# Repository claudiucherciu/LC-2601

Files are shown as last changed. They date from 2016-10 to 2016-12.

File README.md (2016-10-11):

# LibreCube LC-2601 GPS Module

## Overview
The LC-2601 GPS Module is a standalone board that integrates an
GPS receiver and makes its output in terms of position, altitude,
and time available via the CAN bus interface.

## Authors
* Claudiu Cherciu <claudiucherciu@gmail.com>
* Dominik Marszk <dmarszk@gmail.com>
* Artur Scholz <artur.scholz@cubesat.de>

## Acknowledgements
Supported by the ESOC Cybernetic Club.
*SMA connector library from http://www.kicadlib.org/modules/sma_connectors.zip

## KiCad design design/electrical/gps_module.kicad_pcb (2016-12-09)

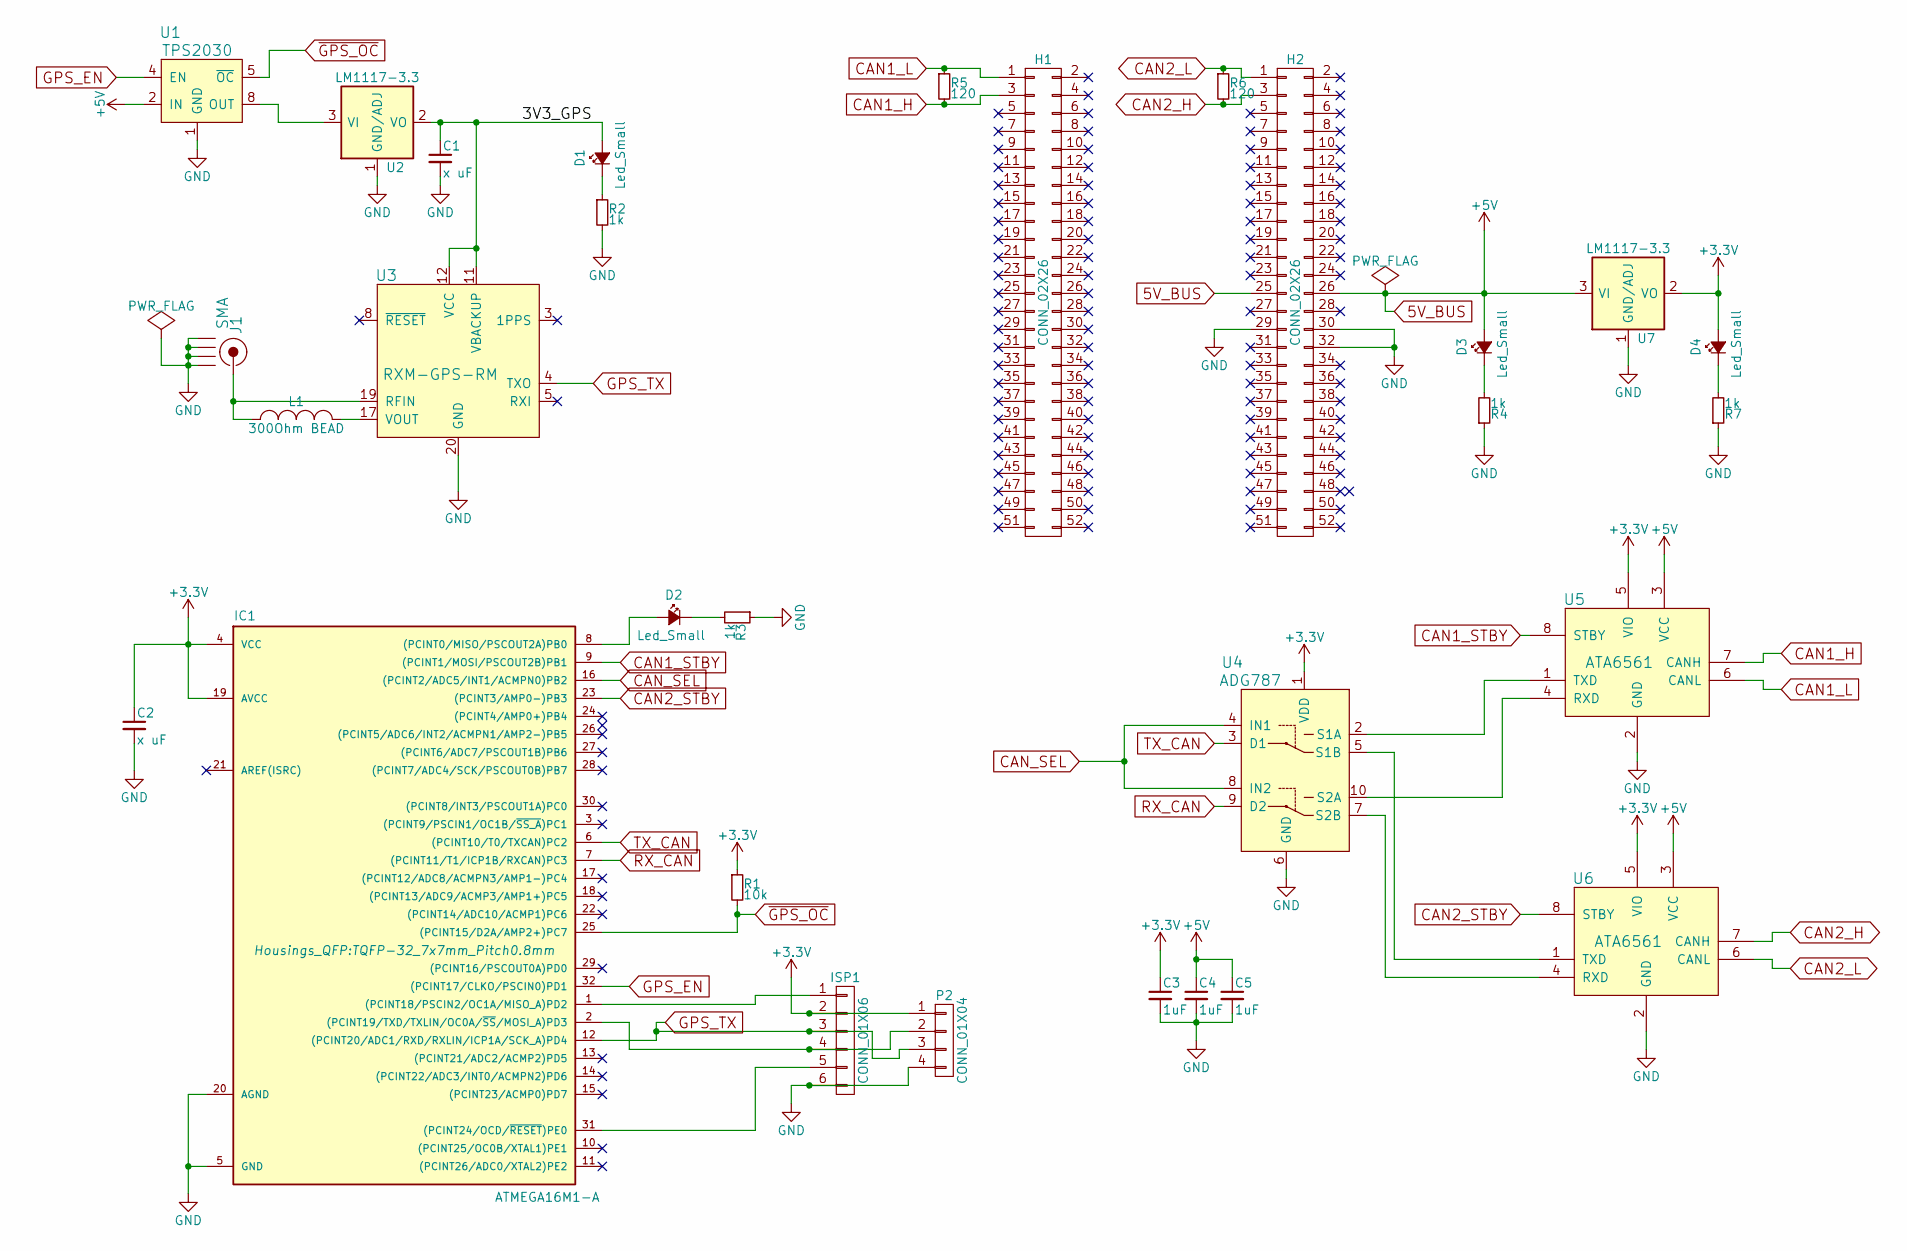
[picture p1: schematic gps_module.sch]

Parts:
C1, C2: x uF; C_0603
C3, C4, C5: 1uF; C_0603
D1, D2, D3, D4: Led_Small; LED_0805
H1, H2: CONN_02X26; Pin_Header_Straight_2x26
IC1: ATMEGA16M1-A; TQFP-32_7x7mm_Pitch0.8mm
ISP1: CONN_01X06; JST_GH_BM06B-GHS-TBT_06x1.25mm_Straight
J1: SMA
L1: 300Ohm BEAD; C_0603
P2: CONN_01X04; JST_GH_BM04B-GHS-TBT_04x1.25mm_Straight
R1: 10k; R_0603_HandSoldering
R2, R3, R4, R7: 1k; R_0603_HandSoldering
R5, R6: 120; R_0603_HandSoldering
U1: TPS2030; SO-8
U2, U7: LM1117-3.3; SOT-223
U3: RXM-GPS-RM
U4: ADG787; MSOP-10_3x3mm_Pitch0.5mm
U5, U6: ATA6561; SO-8

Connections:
5V_BUS: C4.1, C5.1, D3.2 (A), H2.25, H2.26, U1.2 (IN), U1.3 (IN), U5.3 (VCC), U6.3 (VCC), U7.3 (VI)
+3V3: C2.1, C3.1, D4.2 (A), IC1.4 (VCC), IC1.19 (AVCC), ISP1.2, P2.1, R1.1, U4.1 (VDD), U5.5 (VIO), U6.5 (VIO), U7.2 (VO), U7.4 (VO)
/3V3_GPS: C1.1, D1.2 (A), U2.2 (VO), U2.4 (VO), U3.11 (VBACKUP), U3.12 (VCC)
CAN1_H: H1.3, R5.2, U5.7 (CANH)
CAN1_L: H1.1, R5.1, U5.6 (CANL)
CAN1_STBY: IC1.9 ((PCINT1/MOSI/PSCOUT2B)PB1), U5.8 (STBY)
CAN2_H: H2.3, R6.2, U6.7 (CANH)
CAN2_L: H2.1, R6.1, U6.6 (CANL)
CAN2_STBY: IC1.23 ((PCINT3/AMP0-)PB3), U6.8 (STBY)
CAN_SEL: IC1.16 ((PCINT2/ADC5/INT1/ACMPN0)PB2), U4.4 (IN1), U4.8 (IN2)
GND: C1.2, C2.2, C3.2, C4.2, C5.2, H2.29, H2.30, H2.32, IC1.5 (GND), IC1.20 (AGND), ISP1.6, J1.2 (GND1), J1.3 (GND2), J1.4 (GND3), J1.5 (GND4), P2.4, R2.2, R3.1, R4.1, R7.1, U1.1 (GND), U2.1 (GND/ADJ), U3.18 (GND), U3.20 (GND), U3.21 (GND), U3.22 (GND), U4.6 (GND), U5.2 (GND), U6.2 (GND), U7.1 (GND/ADJ)
GPS_EN: IC1.32 ((PCINT17/CLKO/PSCIN0)PD1), U1.4 (EN)
GPS_TX: IC1.12 ((PCINT20/ADC1/RXD/RXLIN/ICP1A/SCK_A)PD4), ISP1.3, P2.3, U3.4 (TXO)
unnamed: D1.1 (K), R2.1
unnamed: D2.1 (K), R3.2
unnamed: D2.2 (A), IC1.8 ((PCINT0/MISO/PSCOUT2A)PB0)
unnamed: D3.1 (K), R4.2
unnamed: D4.1 (K), R7.2
unnamed: IC1.1 ((PCINT18/PSCIN2/OC1A/MISO_A)PD2), ISP1.1
unnamed: IC1.2 ((PCINT19/TXD/TXLIN/OC0A/~SS~/MOSI_A)PD3), ISP1.4, P2.2
unnamed: IC1.31 ((PCINT24/OCD/~RESET~)PE0), ISP1.5
unnamed: J1.1 (RF), L1.1, U3.19 (RFIN)
unnamed: L1.2, U3.17 (VOUT)
unnamed: U1.6 (OUT), U1.7 (OUT), U1.8 (OUT), U2.3 (VI)
unnamed: U4.2 (S1A), U5.1 (TXD)
unnamed: U4.5 (S1B), U6.1 (TXD)
unnamed: U4.7 (S2B), U6.4 (RXD)
unnamed: U4.10 (S2A), U5.4 (RXD)
RX_CAN: IC1.7 ((PCINT11/T1/ICP1B/RXCAN)PC3), U4.9 (D2)
TX_CAN: IC1.6 ((PCINT10/T0/TXCAN)PC2), U4.3 (D1)
~GPS_OC: IC1.25 ((PCINT15/D2A/AMP2+)PC7), R1.2, U1.5 (~OC)

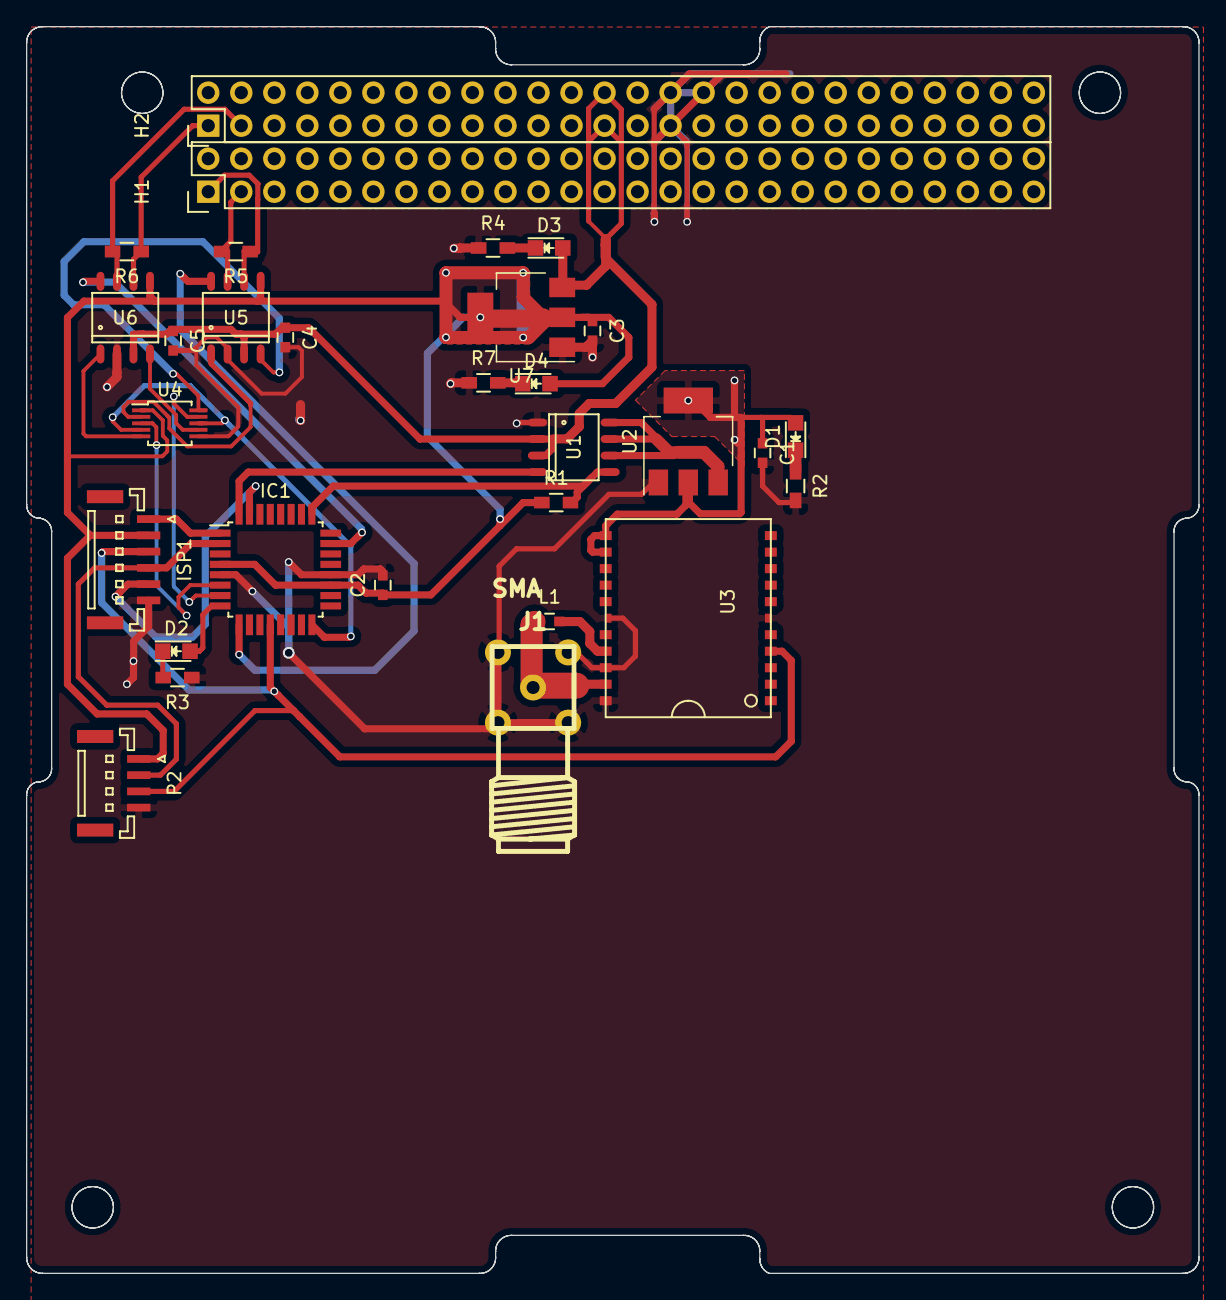
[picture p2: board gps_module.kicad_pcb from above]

Board: 2 copper layers, 90.2 x 95.9 mm, 30 parts (0 on the bottom side), 31 nets.

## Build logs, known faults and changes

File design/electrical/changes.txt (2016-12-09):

08/12/2016
	- Changed C1-5 footprints from 0804 to 0603
	- Changed L1's footprint to 0603
	- IC1 (atmega) and U4 (mux) now powered at 3V3
	- U5 and U6 (transceivers) now use 3.3V as voltage reference
	- C3 assigned to 3V3
	- Added led on PB0 (blinky)
	- Added led on 5V and 3V3
	- Changed /GPS_OC pull-up voltage to 3V3
	- Changed Programming connector voltage to 3V3
	- Added debug port P2 for UART. Please check pinout!
	- Updated SMA connector GND to Passive to remove ERC error.
	- Updated CAN transceiver GND to Passive to remove ERC error.
	- Updated LDO regulator VOUT pin4 to Passive to remove ERC error.
	- Added thermal relief for the 2 voltage regulators

TODO:
	- Update connectors footprint
	- ATTENTION: CAN traces are not perfectly equal..
	- ATTENTION: could prove difficult to connect the gps antenna, in the middle of the board..

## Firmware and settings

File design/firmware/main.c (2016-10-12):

/*! 
\file main.c
\brief		CANopen Slave
\author		Artur Scholz
\date		2016-03-18
\copyright	GNU Public License.
*/
#include <avr/io.h>
#include <avr/interrupt.h>
#include <avr/power.h>
#include <stdio.h>
#define F_CPU		8000000UL	/* 8 MHz */
#include "modules/timer.h"
#include "modules/uart.h"
#include "modules/led.h"
#include "modules/can.h"
#include "modules/gps.h"
#include "canopen/canopen.h"
#include "canopen/canopen_specific.h"
#include "applications/nmea.h"
#include "applications/queue.h"


/* Check if if debug messages shall be sent to uart */
#ifdef DEBUG
	#define debug_output(message)	uart_print_string(message)
#else
	#define debug_output(message)	{}	
#endif


/* Check if if compiler optimizations are enabled */
#ifdef __OPTIMIZE__
	#warning "Compiler optimizations enabled; code may not work as designed"
#endif


int main()
{	
	clock_prescale_set(clock_div_1); /* Set system clock to 8 MHz */
	uart_init(F_CPU, uart_baud_9k6);	
	led_init(LED0);
	led_set(LED0);	
	timer1_init();
	timer1_isr_start();	
	gps_init();	
	canopen_init(F_CPU, can_baud_1M);		
	sei(); /* Enable interrupts */
	debug_output("info: init complete");
	
	for (;;)
	{		
		/* Check if a change of opmode was requested via telecommand */
		if (node_gps_opmode_next != node_gps_opmode_current)
		{
			switch (node_gps_opmode_next)
			{
			case node_gps_opmode_STBY:
				gps_off();
				debug_output("info: now standby");
				node_gps_tm_stat.opmode = node_gps_opmode_STBY;	
				node_gps_opmode_current = node_gps_opmode_next;						
				break;
			case node_gps_opmode_ACTIVE:
				gps_on();
				debug_output("info: now active");
				node_gps_tm_stat.opmode = node_gps_opmode_ACTIVE;
				node_gps_opmode_current = node_gps_opmode_next;
				break;
			default:
				debug_output("warning: opmode not valid");
				node_gps_opmode_next = node_gps_opmode_current;
				break;
			}	
		}
		
		/* Check if SYNC was received */
		if (node_gps_sync_received)
		{
			debug_output("info: SYNC");
			node_gps_sync_received = 0;	
			canopen_send_tpdo(CANOPEN_TPDO_TM_STAT_INDEX);
			canopen_send_tpdo(CANOPEN_TPDO_TM_UTC_INDEX);
			canopen_send_tpdo(CANOPEN_TPDO_TM_POS_INDEX);		
			canopen_send_tpdo(CANOPEN_TPDO_TM_ALT_INDEX);	
		}
		
		/* Check if a TC request for telemetry is in the queue */		
		while (queue_is_emtpy() == FALSE)
		{			
			queue_remove(&queue_buffer);							
			switch (queue_buffer)
			{
			case NODE_GPS_TM_STAT_ID:
				debug_output("info: STAT");	
				canopen_send_tpdo(CANOPEN_TPDO_TM_STAT_INDEX);
				break;
			case NODE_GPS_TM_UTC_ID:
				debug_output("info: UTC");
				canopen_send_tpdo(CANOPEN_TPDO_TM_UTC_INDEX);
				break;								
			case NODE_GPS_TM_POS_ID:
				debug_output("info: POS");
				canopen_send_tpdo(CANOPEN_TPDO_TM_POS_INDEX);
				break;						
			case NODE_GPS_TM_ALT_ID:
				debug_output("info: ALT");
				canopen_send_tpdo(CANOPEN_TPDO_TM_ALT_INDEX);
				break;								
			}						
		}
		
		if (node_gps_opmode_current == node_gps_opmode_ACTIVE)
		{
			uart_buffer = 0;
			if (uart_read(&uart_buffer) == err_OK)
			{
				if (uart_buffer == NMEA_MSG_START) /* Check if start of sequence found */
				{
					/* Read the message identifier */
					uart_read_array((uint8_t*)(&nmea.msg_buffer[0]), NMEA_MSG_ID_LENGTH); 
					/* Check if this is a GGA message */
					if (nmea_check_msg(&nmea) == err_OK)
					{
						/* Read the rest of the message */
						uart_read_string(&nmea.msg_buffer[NMEA_MSG_ID_LENGTH], 
													NMEA_MSG_LENGTH - NMEA_MSG_ID_LENGTH);
						/* Parse the message content and check for its validity */							
						nmea_parse(&nmea); 
						node_gps_tm_stat.valid		= nmea.is_valid;
				
						/* the following outputs are for test purposes */		
						if (nmea.is_valid) 
						{						
							/* Update the canopen process data block variables */
							node_gps_tm_utc.hour		= nmea.hour;
							node_gps_tm_utc.min			= nmea.min;
							node_gps_tm_utc.sec			= nmea.sec;
							node_gps_tm_pos.lat			= nmea.lat;
							node_gps_tm_pos.lat_sub_1	= nmea.lat_sub >> 8;
							node_gps_tm_pos.lat_sub_0	= nmea.lat_sub & 0xFF;
							node_gps_tm_pos.lon_1		= nmea.lon >> 8;
							node_gps_tm_pos.lon_0		= nmea.lon & 0xFF;
							node_gps_tm_pos.lon_sub_1	= nmea.lon_sub >> 8;
							node_gps_tm_pos.lon_sub_0	= nmea.lon_sub & 0xFF;		
							node_gps_tm_alt.alt_1		= nmea.alt >> 8;
							node_gps_tm_alt.alt_0		= nmea.alt & 0xFF;
							node_gps_tm_alt.alt_sub		= nmea.alt_sub;	
						
							/* Debug output */
							char buff[80];		
							sprintf(buff, "Time %02d:%02d:%02d", nmea.hour, nmea.min, nmea.sec);			
							debug_output(buff);				
							sprintf(buff, "Lat %d.%d", nmea.lat, nmea.lat_sub);
							debug_output(buff);
							sprintf(buff, "Lon %d.%d", nmea.lon, nmea.lon_sub);
							debug_output(buff);	
							sprintf(buff, "Alt %d.%d", nmea.alt, nmea.alt_sub);			
							debug_output(buff);													
						}
						else
						{
							debug_output(".");		
						}					
					}
				}
			}
		}
	}
	return 0;
}


/*! Timer1 interrupt service routine - Handle redundancy management */
ISR(TIMER1_COMPA_vect) 
{ 
	static uint8_t* ntoggle = &canopen_redundancy_management.ntoggle;
	static uint8_t* ctoggle = &canopen_redundancy_management.ctoggle;
	
	canopen_consumer_heartbeat_counter_ms += TIMER1_TICK_MS;
	
	/* Check if Heartbeat is enabled */
	if (canopen_consumer_heartbeat_time > 0) 
	{
		/* Check if Heartbeat has expired */
		if (canopen_consumer_heartbeat_counter_ms 
				>= canopen_consumer_heartbeat_time) 
		{
			canopen_consumer_heartbeat_counter_ms = 0;
			canopen_consumer_heartbeat_ttoggle_counter++;
			if (canopen_consumer_heartbeat_ttoggle_counter 
					>= canopen_redundancy_management.ttoggle)
			{
				/* Switch the bus if Ntoogle limit has not yet been reached */
				if (*ctoggle < *ntoggle)
				{
					canopen_bus_switchover(); 
					*ctoggle = *ctoggle + 1;
					debug_output("info: bus switched");
					node_gps_tm_stat.bus_switch_cnt++;
				}
				else
				{
					debug_output("warning: switch limit");
				}
				canopen_consumer_heartbeat_ttoggle_counter = 0;
			}	
		}
	}
}


/*! CAN interrupt service routine */
ISR(CAN_INT_vect) 
{ 
	static uint8_t* ctoggle = &canopen_redundancy_management.ctoggle;
	static struct can_frame_t can_frame;
	uint8_t page_saved;	
	uint8_t i;

	/* RX interrupt, broadcast frames from master */
	if (CANSIT2 & (1 << CAN_MOB_RX_MASTER)) 	
	{
		page_saved = CANPAGE;
		CANPAGE = CAN_MOB_RX_MASTER << MOBNB0;;
		can_frame.id = (CANIDT1 << 3) | (CANIDT2 >> 5);		
		can_frame.dlc = CANCDMOB & 0x0F; 
		for (i = 0; i < can_frame.dlc; i++) /* Read data */
		{
			can_frame.data[i] = CANMSG;
		}
		CANSTMOB &= ~(1 << RXOK); /* Clear rx interrupt flag */	
		CANCDMOB = 1 << CONMOB1; /* Enable reception again */	
		CANPAGE = page_saved;
		
		switch (can_frame.id)
		{
		case canopen_cob_id_HEARTBEAT:
			canopen_consumer_heartbeat_counter_ms = 0;
			canopen_consumer_heartbeat_ttoggle_counter = 0;
			*ctoggle = 0;
			if (canopen_get_state() == canopen_state_PRE_OPERATIONAL) 
			{
				canopen_set_state(canopen_state_OPERATIONAL);
			}
			led_toggle(LED0);
			break;
		case canopen_cob_id_SYNC:
			node_gps_sync_received = 1;
			break;
		}	
	}
	
	/* RX interrupt, dedicated frames (telecommands) from master */		
	if (CANSIT2 & (1 << CAN_MOB_RX_NODE)) 
	{
		page_saved = CANPAGE;
		CANPAGE = CAN_MOB_RX_NODE << MOBNB0;;
		can_frame.id = (CANIDT1 << 3) | (CANIDT2 >> 5);		
		can_frame.dlc = CANCDMOB & 0x0F; 
		for (i = 0; i < can_frame.dlc; i++) /* read data */
		{
			can_frame.data[i] = CANMSG;
		}
		CANSTMOB &= ~(1 << RXOK); /* Clear rx interrupt flag */	
		CANCDMOB = 1 << CONMOB1; /* Enable reception again */	
		CANPAGE = page_saved;
		
		if (canopen_receive_rpdo(CANOPEN_RPDO_TC_OPMODE_INDEX, &can_frame) == err_OK)
		{
			node_gps_opmode_next = node_gps_tc_opmode.opmode; 
		}
		else if (canopen_receive_rpdo(CANOPEN_RPDO_TC_REQUEST_TM_INDEX, &can_frame) == err_OK)
		{
			/* Add the tm request in the queue */
			queue_add(node_gps_tc_request_tm.request_tm_id); 
		}		
	}
}

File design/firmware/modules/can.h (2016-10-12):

/*! 
\file can.h
\brief		Functions to initialize, send, and receive over CAN bus.
\author		Artur Scholz
\date		2016-02-08
\copyright	GNU Public License.
*/ 
#ifndef CAN_H
#define CAN_H


/* Constants & Macros ********************************************************/


#define CAN_MOB_MAX			6		/*!< Max number of CAN message objects */
#define CAN_TRX_PORT		PORTB	/*!< CAN transceiver interface port */
#define CAN_TRX_DDR			DDRB	/*!< CAN trx data direction bit */
#define CAN_TRX1_PIN_STBY	PB1		/*!< STBY (standby) pin (9) */
#define CAN_TRX_PIN_MUX		PB2		/*!< MUX pin (16) */
#define CAN_TRX2_PIN_STBY	PB3		/*!< STBY (standby) pin (23) */


/* Type Definitions **********************************************************/


/*!
\enum		err_t
\brief		Error codes 
*/
#ifndef ERR_T
#define ERR_T
typedef enum 
{
   err_OK	= 0,
   err_FAIL	= -1
} err_t;
#endif


/*!
\enum		can_trx
\brief		An enum for the selectable CAN transceivers 
*/
enum can_trx_t
{
	can_TRX1,
	can_TRX2
};


/*!
\enum		can_baud_t
\brief		Baud rate of CAN controller
*/
enum can_baud_t 
{
   can_baud_125K	= 125,
   can_baud_250K	= 250,
   can_baud_500K	= 500,
   can_baud_1M		= 1000
};


/*!
\enum		can_mode_t
\brief		Mode of CAN controller
*/
enum can_mode_t 
{
   can_mode_STOP,		/*!< Stop the controller */
   can_mode_START		/*!< Set controller into normal operation */
};


/*!
\enum		can_trx_mode_t
\brief		Mode of CAN transceiver
*/
enum can_trx_mode_t 
{
   can_trx_mode_ON,		/*!< Set transceiver into normal operation */
   can_trx_mode_STBY	/*!< Set transceiver into standby mode */
};


/* Structs *******************************************************************/


/*!
\struct		can_frame_t		
\brief		CAN frame structure 
*/
struct can_frame_t
{
	/*! 11-bit standard frame identifier */
	uint16_t id;
	/*! Id mask, must be set properly to receive frames */		
	uint16_t id_mask;
	/* 4-bit data length code */	
	uint8_t dlc;	
	/* Frame data stored as array of 8 bytes */ 	
	uint8_t data[8];	
};


/* Global Variables **********************************************************/


uint8_t can_trx_active; /*!< The currently active CAN transceiver */	


/* Functions *****************************************************************/


/*!
\brief		Initialize CAN interface
\param		sysclock_Hz		System clock frequency
\param		can_baud		Desired baud rate
\details	Initialize the CAN interface for reception and transmission
			of CAN frames at the supported baud rates.
*/
void can_init(const uint32_t sysclock_Hz, const enum can_baud_t can_baud);


/*!
\brief		Set mode of CAN controller
\param		can_mode		Desired mode from #can_mode enum.
*/
void can_set_mode(const enum can_mode_t can_mode);


/*!
\brief		Configure a MOb for receiving of CAN frames
\details	This function defines for the selected MOb the mask and id of
			the CAN messages to filter for and enables the interrupt of 
			the selected MOb.
*/
void can_configure_receive(const uint8_t mob, const struct can_frame_t* can_frame);


/*!
\brief		Transmit a CAN frame
\param		mob				MOb to be used
\param		can_frame		Pointer to buffer of CAN frame
\return		If the frame cannot be sent because the controller is busy,
			the function will return \c err_FAIL. It will also return a
			\c err_FAIL if the sending did not succeed, for example due
			to a frame acceptance error (i.e. no other node listening).
			If sending was successful it will return \c err_OK.
*/
err_t can_send(const uint8_t mob, const struct can_frame_t* can_frame);


/*!
\brief		Initialize CAN transceiver interface
\param		sysclock_Hz		System clock frequency
\param		can_baud		Desired baud rate
\details	This function sets the pins of the microntroller for mux and
			standby to output mode and sets both transceiver to standby.
*/
void can_trx_init(void);


/*!
\brief		Select the active CAN transceiver
\param		can_trx		Transceiver to be active, see #can_trx_t enum.
\details	This function sets the global variable that indicates the
			active transceiver. Only one transceiver is	active at a time.
			With the selected active transceiver, any further control
			commands will affect the now selected active transceiver.
*/
void can_trx_select_active(const enum can_trx_t can_trx);


/*!
\brief		Set mode of CAN transceiver
\param		can_trx_mode	Desired mode from #can_trx_mode enum.
\details	The mode will be set for the active transceiver.
*/
void can_trx_set_mode(const enum can_trx_mode_t can_trx_mode);


/*!
\brief		Switch over to the other CAN transceiver
\details	This function checks which is the active CAN transceiver and
			then calls #can_trx_set_mode to activate the other one.
*/
void can_trx_toogle_active(void);


#endif /* CAN_H */

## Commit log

2016-10-10 Initial add of kicad design files: sch, lib, some layout
    [gps_can_v0.1.kicad_pcb, gps_can_v0.1.sch]
2016-10-11 Renamed sch folder to /design/electrical
    [gps_can_v0.1.kicad_pcb, gps_can_v0.1.sch]
2016-10-11 Added ~GPS_OC as input signal to uC
    [gps_can_v0.1.sch]
2016-10-11 First layout attempt. Gerber files included.
    [gps_can_v0.1.kicad_pcb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]
2016-10-11 add firmware
    [gps_can_v0.1.sch]
2016-10-11 Removed voltage divider on GPS_RX, pullup resistor ~RESET for GPS and S3 & S4 as +5V supply. Added pullup resistor for ~GPS_OC. Solved most ERC errors.
    [gps_can_v0.1.sch]
2016-10-11 Changed pins function (direction) to solve ERC errors in schematics
2016-10-11 Updated PCB layout and Gerbers
    [gps_can_v0.1.kicad_pcb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]
2016-10-11 Added pad for alternative +5V supply.
    [gps_can_v0.1.kicad_pcb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]
2016-10-12 some folder rearrangement
    [gps_can_v0.1-B.Cu.gbr, gps_can_v0.1-B.SilkS.gbr, gps_can_v0.1-F.Cu.gbr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]
2016-10-12 rename file
    [gps_module.kicad_pcb, gps_module.sch]
2016-10-14 Added decupling capacitors for CAN and MUX
    [gps_can_v0.1.drl, gps_module-B.Cu.gbl, gps_module-B.Mask.gbs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]
2016-10-15 create new gerber files
    [gps_can_v0.1-B.SilkS.gbr, gps_can_v0.1-F.SilkS.gbr, gps_module-B.Cu.gbr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]
2016-10-19 Rotated GPS module, increased GPS antenna track width
    [gps_module-B.Cu.gbl, gps_module-B.Mask.gbs, gps_module-B.Paste.gbp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]
2016-12-09 Changed IC to 3.3V, added 1 LDO, 2 Leds, 1uart port, changed footprints to 0603, updated layout.
    Still 2 unconnected traces reported by Kicad.
    [gps_module.kicad_pcb, gps_module.sch]
2016-12-09 add 3v3 converter and LEDs
    [gps_module.kicad_pcb, gps_module.sch]
2016-12-09 fix unconnected track
    [gps_module.kicad_pcb]
